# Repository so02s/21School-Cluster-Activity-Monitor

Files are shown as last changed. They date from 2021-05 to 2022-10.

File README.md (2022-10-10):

# 21School-Cluster-Activity-Monitor
### Description
In order to visualize clusters computers accesibility for students and make finding a coding place for oneself easier, School 21's Lab Manager Freimor (Ricky in School 21) came up with the idea of autonomous Cluster Activity Monitor.
It should be set up on each of the School's floors. We've managed to set it up on the 2nd floor.
Monitor has a map embedded in its graphics. It lights up LEDs, showing which Mac seats are occupied, which are free to use and other types of seat status. It's connected to a local network and pulls data from the metrics data-point server. 
* Monitor shows seats that are either taken, free, covid-free or used for exam.
* It also lights up the viewer's position on the map.
* Brightness of the LED is dependant on ambient light level, due to embedded light sensor.
* It should potentially support extra add-ons.



### Monitor consists of:
* 5 front PCB's which we call "modules", with school claster names (Atrium, Illusion, Oasis, Atlantis and Mirage)
  * ~450 SK9822 2020 leds
  * STM32F030* microcontroller
* 1 "motherboard" PCB
  * Raspberry Pi Zero W
  * ADS1115 for photoresistor
* Mean Well IRM-60-5ST power supply
* 3D printed skeleton structure
  * M1.2 inserted nuts and bolts for fixing modules in 3d printed front layer
  * M4 inserted nuts and bolts for fixing front layer to skeleton main body
  * 4 wall plug for fixing main body to wall
* Front PCB's shield made of polycarbonate sheet



<details><summary>Photos</summary>
<p>

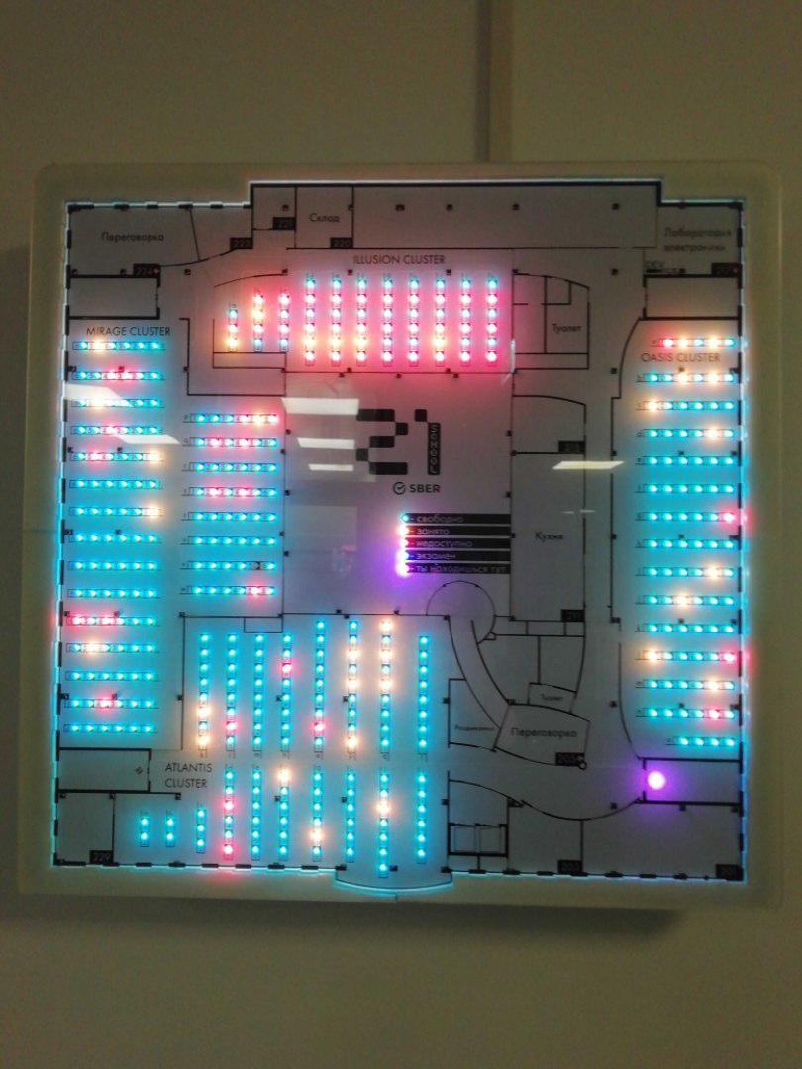
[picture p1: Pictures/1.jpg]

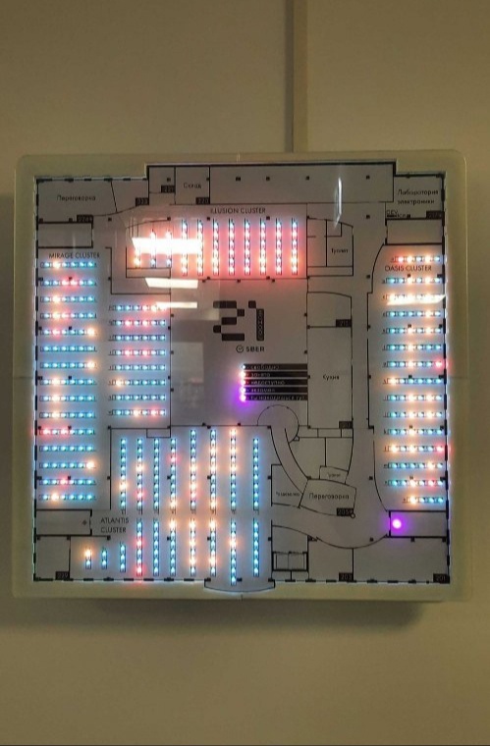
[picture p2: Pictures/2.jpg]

</p>
</details>

Done by team: Ricky, Bomanyte.

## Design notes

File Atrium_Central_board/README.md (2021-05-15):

# Atrium Central board layout

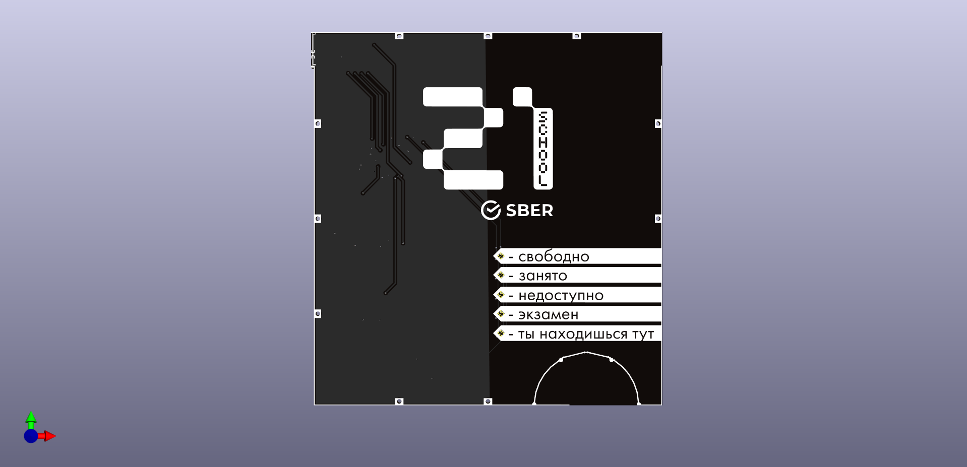
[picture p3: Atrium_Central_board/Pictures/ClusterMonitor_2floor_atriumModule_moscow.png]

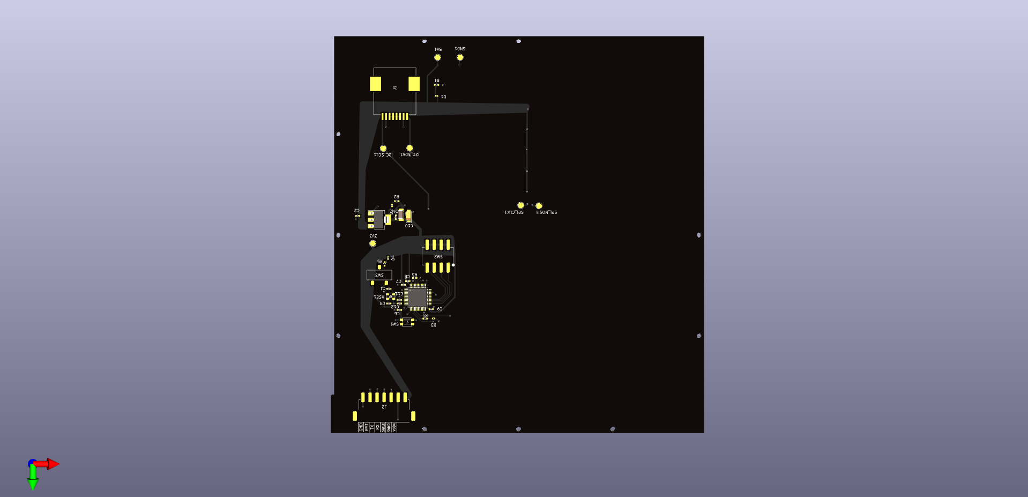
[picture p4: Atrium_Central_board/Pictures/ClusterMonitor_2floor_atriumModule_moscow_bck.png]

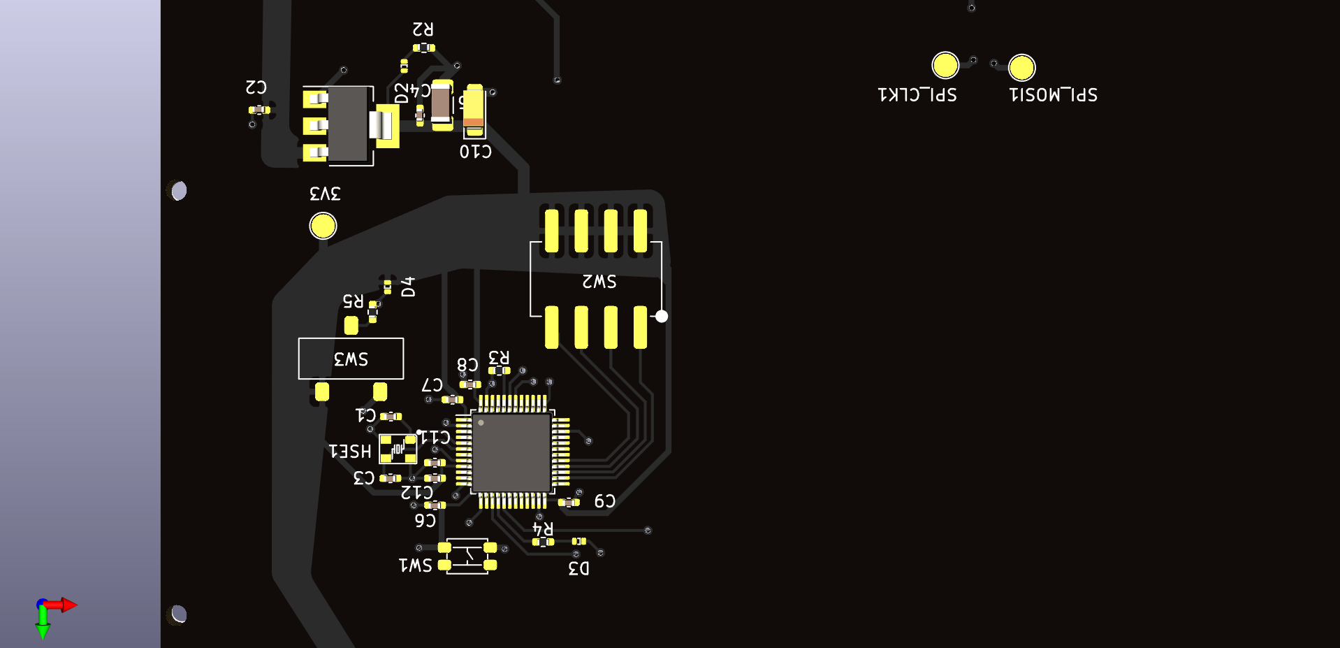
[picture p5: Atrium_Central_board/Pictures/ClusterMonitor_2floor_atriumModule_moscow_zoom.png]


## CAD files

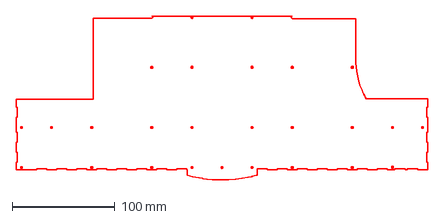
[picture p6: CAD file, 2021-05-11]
Atlantis_board/CM_2f_atlantis_outline_with_holes.dxf
400.0 x 159.3 mm

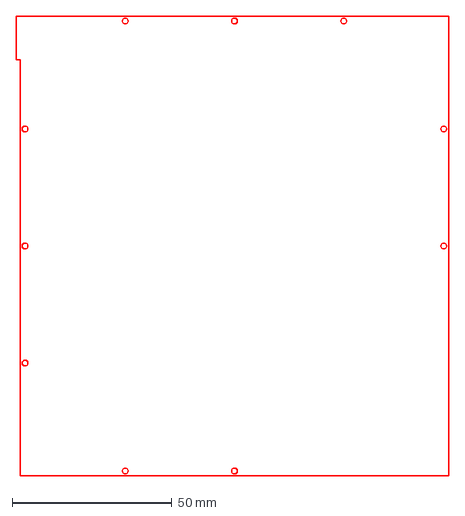
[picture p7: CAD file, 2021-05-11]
Atrium_Central_board/Silk/CM_2f_atrium_outline_with_holes.dxf
135.1 x 143.6 mm

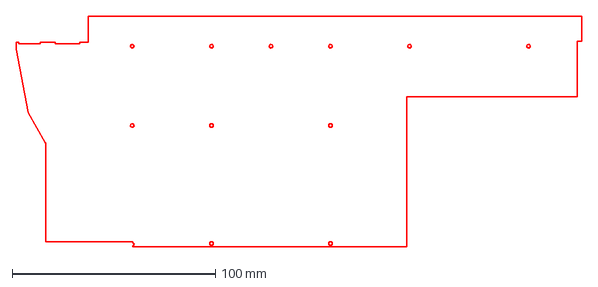
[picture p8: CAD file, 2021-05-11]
Illusion_board/CM_2f_illusion_outline_with_holes.dxf
278.6 x 113.3 mm

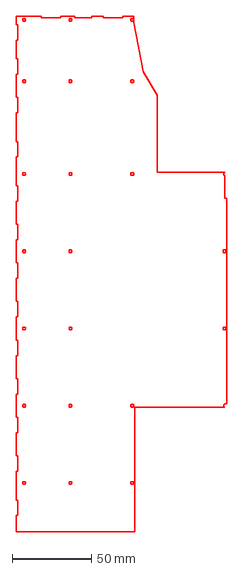
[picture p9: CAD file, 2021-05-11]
Mirage_board/CM_2f_mirage_outline_with_holes.dxf
132.8 x 325.5 mm

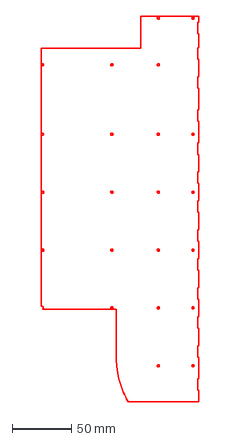
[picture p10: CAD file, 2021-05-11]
Oasis_board/CM_2f_oasis_outline_with_holes.dxf
132.8 x 325.1 mm

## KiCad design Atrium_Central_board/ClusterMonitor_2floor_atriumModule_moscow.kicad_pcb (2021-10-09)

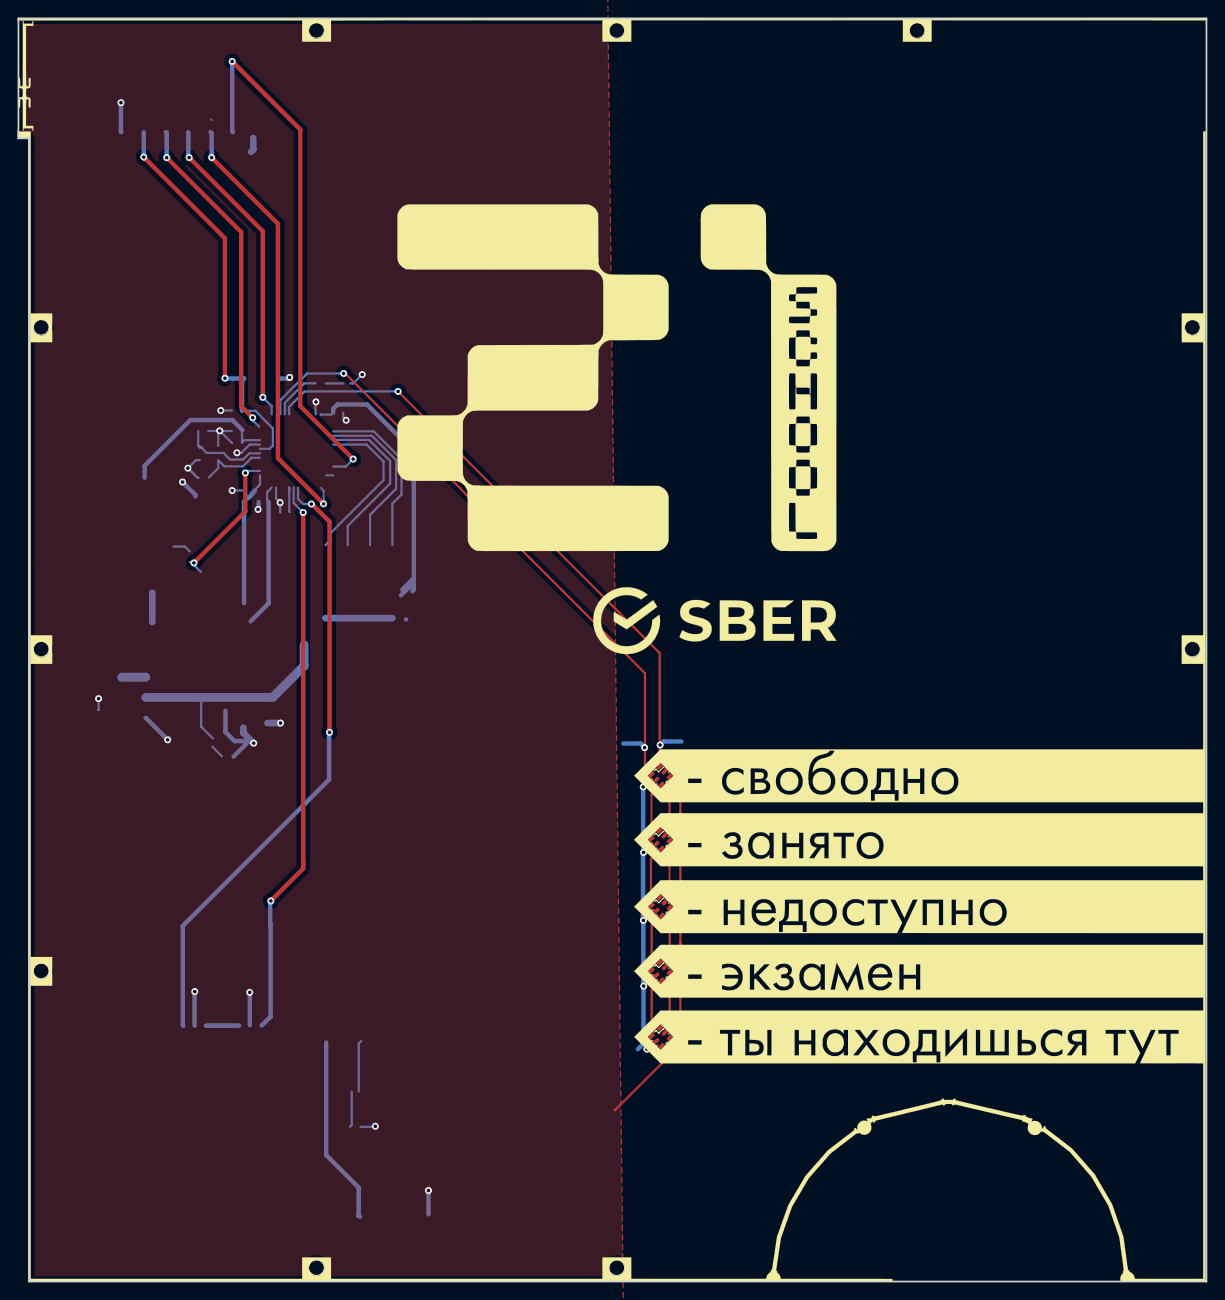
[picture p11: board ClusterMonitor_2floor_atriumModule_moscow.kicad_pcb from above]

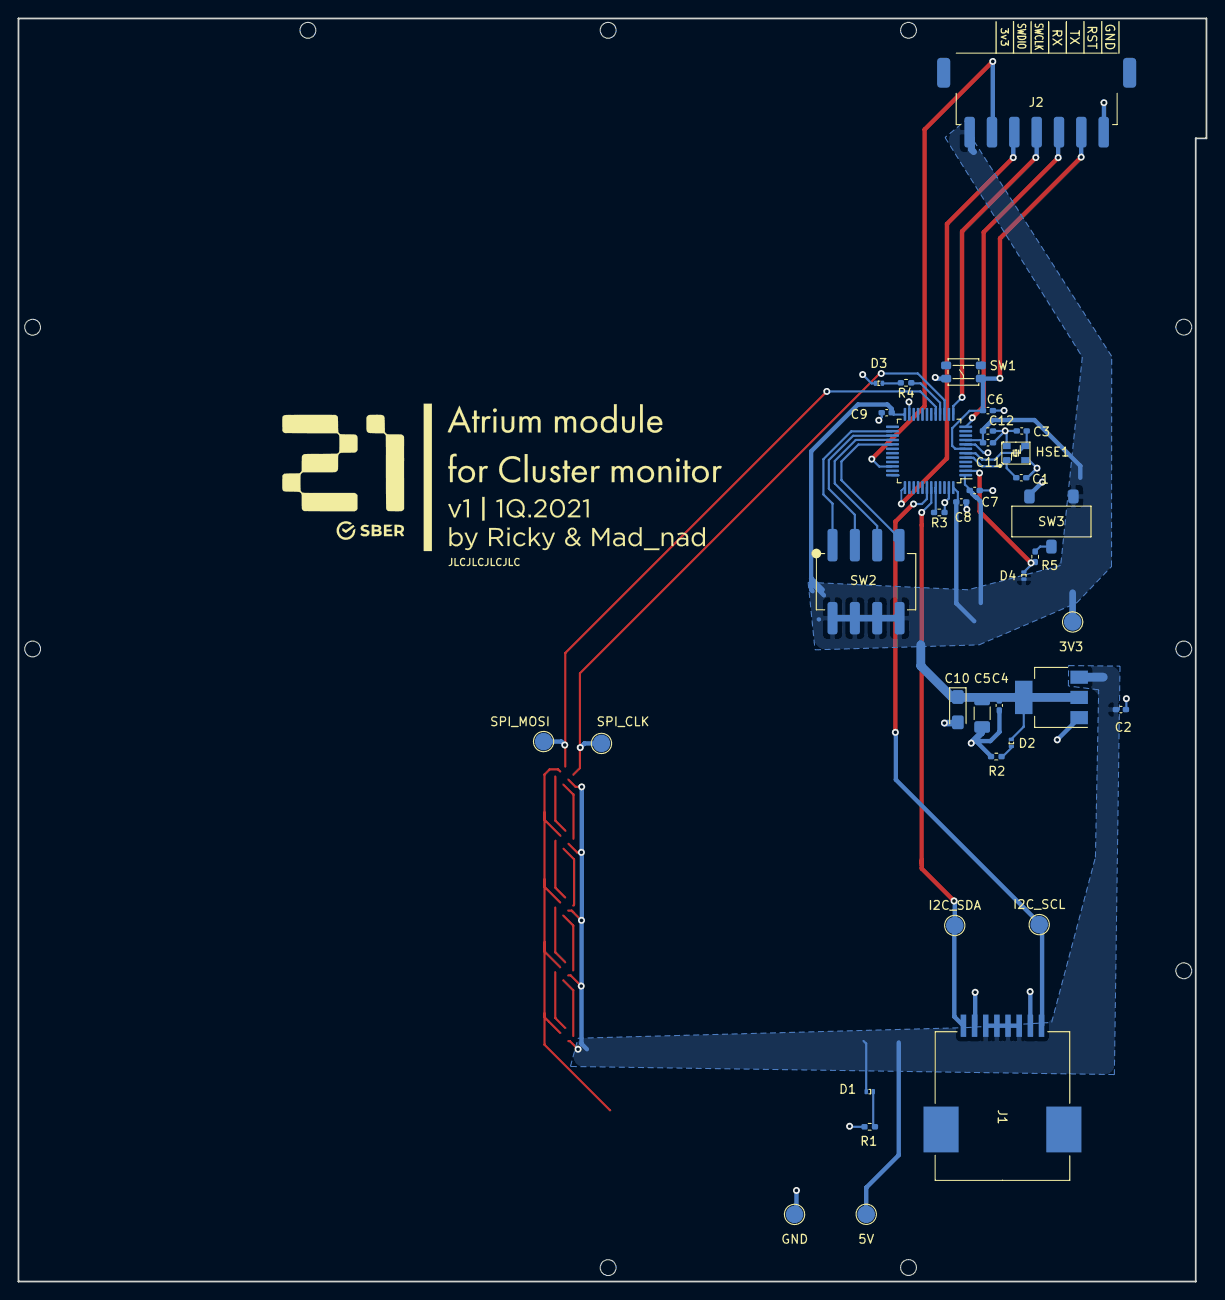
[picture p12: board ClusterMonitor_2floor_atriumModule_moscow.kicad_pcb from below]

Board: 2 copper layers, 135.1 x 143.6 mm, 41 parts (36 on the bottom side), 33 nets.

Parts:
3V3: TEST2; Pad_test
5V: TEST1; Pad_test
C1, C3: 15pF; C_0402_1005Metric_Pad0.74x0.62mm_HandSolder
C2, C4: 10uF; C_0402_1005Metric_Pad0.74x0.62mm_HandSolder
C5: 22uF tantal; C_1206_3216Metric_Pad1.33x1.80mm_HandSolder
C6: 0.1uF; C_0402_1005Metric_Pad0.74x0.62mm_HandSolder
C7, C8, C9: 100nF; C_0402_1005Metric_Pad0.74x0.62mm_HandSolder
C10: 4.7uF; CP_EIA-3216-10_Kemet-I_Pad1.58x1.35mm_HandSolder
C11: 10nF; C_0402_1005Metric_Pad0.74x0.62mm_HandSolder
C12: 1uF; C_0402_1005Metric_Pad0.74x0.62mm_HandSolder
D1: LED Blue (5v Power ON); LED_SMD_0402
D2: LED Red (3v3 Power ON); LED_SMD_0402
D3: Orange LED; LED_SMD_0402
D4: Purple LED; LED_SMD_0402
GND: TEST3; Pad_test
HSE1: Crystal_gnd24; ResonatorSMD_4pin(2,4GND)_KDS_1C232000AA0B
I2C_SCL: TEST4; Pad_test
I2C_SDA: TEST5; Pad_test
J1: RJ32_Shielded; rj45_molex_smd_44144-0003
J2: Conn_01x07; connector_7pin_xh2.54__lcsc_c146123_
LED1, LED2, LED3, LED4, LED5: SK9822-EC20
R1, R2, R4, R5: 1k5; R_0402_1005Metric_Pad0.72x0.64mm_HandSolder
R3: 10k; R_0402_1005Metric_Pad0.72x0.64mm_HandSolder
SPI_CLK: TEST6; Pad_test
SPI_MOSI: TEST7; Pad_test
SW1: SW_SPST; SW_SMD_XKB_(TS-1809SM-C)
SW2: ADDRESS_SELECT; SW_4poles_(LCSC_C3693)
SW3: SW_SPDT; SW_SMD_XKB_(SS-3235D-03-L1)
U1: AMS1117-3.3; SOT-223-3_TabPin2
U2: STM32F030C8Tx; LQFP-48_7x7mm_P0.5mm

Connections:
+5V: 5V.1, C2.1, D1.2, J1.3, J1.4, J1.5, J1.6, LED1.5, LED2.5, LED3.5, LED4.5, LED5.5, U1.3
C_RST: C6.2, J2.6, SW1.1, U2.7
GND: C1.2, C2.2, C3.2, C4.2, C5.2, C6.1, C7.2, C8.2, C9.2, C10.2, C11.2, C12.1, D3.1, GND.1, HSE1.2, HSE1.4, J1.2, J1.7, J2.7, LED1.2, LED2.2, LED3.2, LED4.2, LED5.2, R1.2, R2.2, R3.1, SW1.2, SW3.3, U1.1, U2.8, U2.23, U2.47
HSE_IN: C1.1, HSE1.1, U2.5
HSE_OUT: C3.1, HSE1.3, U2.6
I2C1_SCL: I2C_SCL.1, J1.8, U2.42
I2C1_SDA: I2C_SDA.1, J1.1, U2.43
unnamed: D1.1, R1.1
unnamed: D2.1, R2.1
unnamed: D3.2, R4.2
unnamed: LED1.1, LED2.3
unnamed: LED1.6, LED2.4
unnamed: LED2.1, LED3.3
unnamed: LED2.6, LED3.4
unnamed: LED3.1, LED4.3
unnamed: LED3.6, LED4.4
unnamed: LED4.1, LED5.3
unnamed: LED4.6, LED5.4
unnamed: R3.2, U2.44
unnamed: R4.1, U2.16
unnamed: R5.2, SW3.2
REG_1b: SW2.1, U2.26
REG_2b: SW2.2, U2.27
REG_3b: SW2.3, U2.28
REG_4b: SW2.4, U2.29
SPI1_CLK: LED1.4, SPI_CLK.1, U2.15
SPI1_MOSI: LED1.3, SPI_MOSI.1, U2.17
SWITCH_MODE: D4.1, R5.1, U2.2
SYS_JTCK-SWCLK: J2.3, U2.37
SYS_JTMS-SWDIO: J2.2, U2.34
USART2_RX: J2.4, U2.13
USART2_TX: J2.5, U2.12
VDDA: 3V3.1, C4.1, C5.1, C7.1, C8.1, C9.1, C10.1, C11.1, C12.2, D2.2, D4.2, J2.1, SW2.5, SW2.6, SW2.7, SW2.8, SW3.1, U1.2, U2.1, U2.9, U2.24, U2.48

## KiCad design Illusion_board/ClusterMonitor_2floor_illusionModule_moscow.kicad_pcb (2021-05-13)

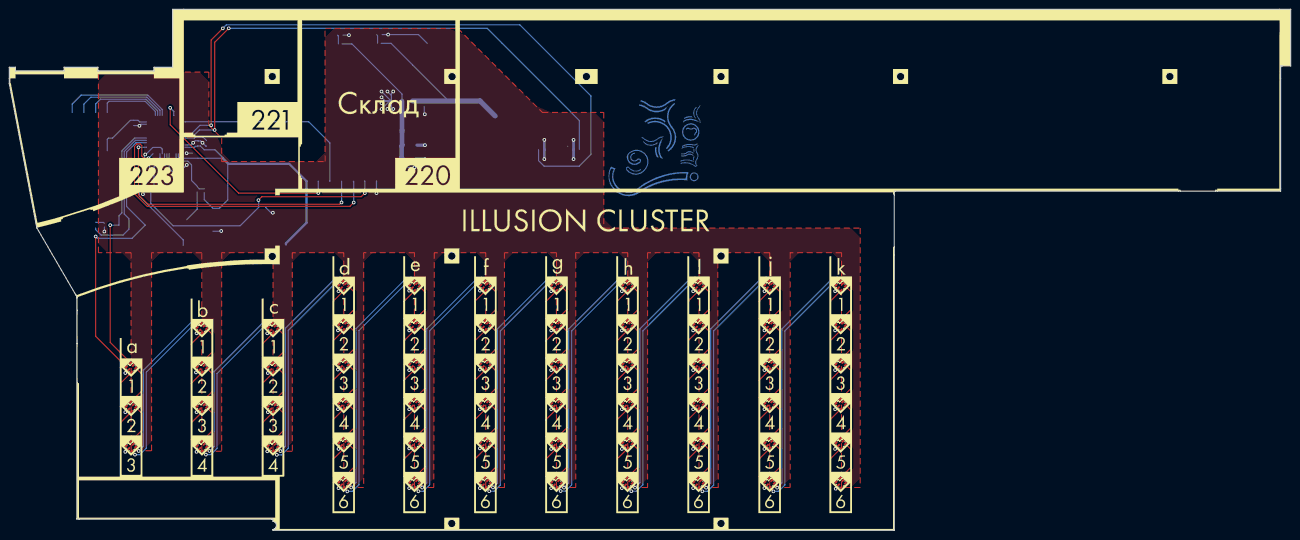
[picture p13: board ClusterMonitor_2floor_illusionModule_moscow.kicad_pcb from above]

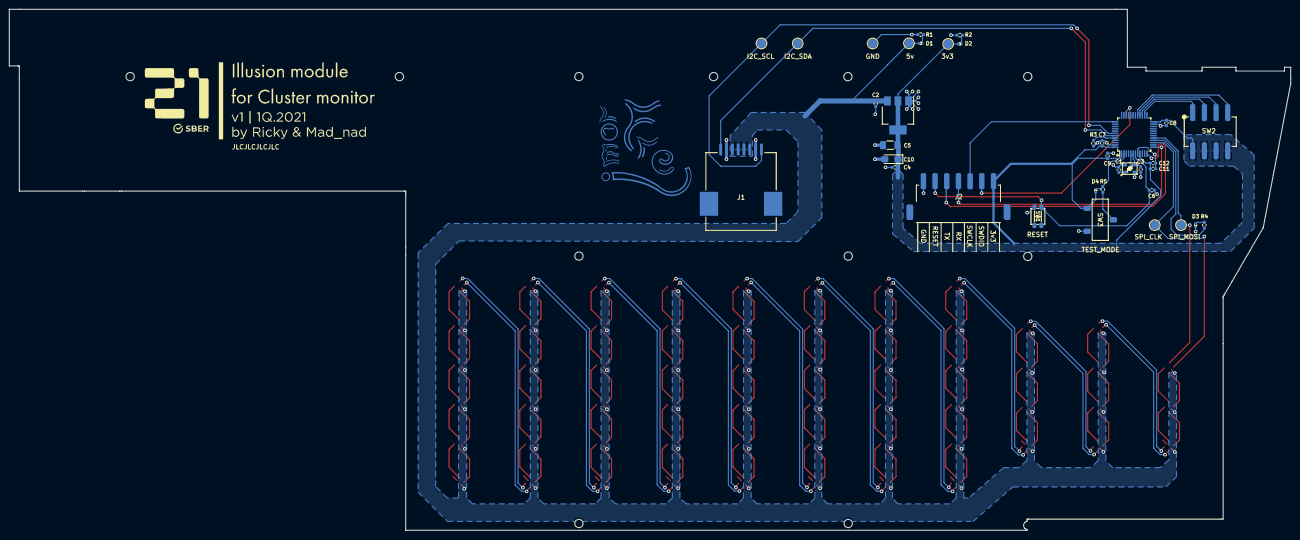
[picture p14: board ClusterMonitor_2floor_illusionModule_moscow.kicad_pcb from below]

Board: 2 copper layers, 278.6 x 113.3 mm, 95 parts (36 on the bottom side), 141 nets.

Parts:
C1, C3: 15pF; C_0402_1005Metric_Pad0.74x0.62mm_HandSolder
C2, C4: 10uF; C_0402_1005Metric_Pad0.74x0.62mm_HandSolder
C5: 22uF tantal; C_1206_3216Metric_Pad1.33x1.80mm_HandSolder
C6: 0.1uF; C_0402_1005Metric_Pad0.74x0.62mm_HandSolder
C7, C8, C9: 100nF; C_0402_1005Metric_Pad0.74x0.62mm_HandSolder
C10: 4.7uF; CP_EIA-3216-10_Kemet-I_Pad1.58x1.35mm_HandSolder
C11: 10nF; C_0402_1005Metric_Pad0.74x0.62mm_HandSolder
C12: 1uF; C_0402_1005Metric_Pad0.74x0.62mm_HandSolder
D1: LED Blue (5v Power ON); LED_SMD_0402
D2: LED Red (3v3 Power ON); LED_SMD_0402
D3: Orange LED; LED_SMD_0402
D4: Purple LED; LED_SMD_0402
HSE1: Crystal_gnd24; ResonatorSMD_4pin(2,4GND)_KDS_1C232000AA0B
J1: RJ45_Molex_smd_44144-0003
J2: Conn_01x07; Connector_7pin_XH2.54_(LCSC_C146123)
LED-a-1, LED-a-2, LED-a-3: SK9822-EC20
LED-b-1, LED-b-2, LED-b-3, LED-b-4: SK9822-EC20
LED-c-1, LED-c-2, LED-c-3, LED-c-4: SK9822-EC20
LED-d-1, LED-d-3, LED-d-4, LED-d-5, LED-d-6: SK9822-EC20
LED-d-e: SK9822-EC20
LED-e-1, LED-e-2, LED-e-3, LED-e-4, LED-e-5, LED-e-6: SK9822-EC20
LED-f-1, LED-f-2, LED-f-3, LED-f-4, LED-f-5, LED-f-6: SK9822-EC20
LED-g-1, LED-g-2, LED-g-3, LED-g-4, LED-g-5, LED-g-6: SK9822-EC20
LED-h-1, LED-h-2, LED-h-3, LED-h-4, LED-h-5, LED-h-6: SK9822-EC20
LED-i-1, LED-i-2, LED-i-3, LED-i-4, LED-i-5, LED-i-6: SK9822-EC20
LED-j-1, LED-j-2, LED-j-3, LED-j-4, LED-j-5, LED-j-6: SK9822-EC20
LED-k-1, LED-k-2, LED-k-3, LED-k-4, LED-k-5, LED-k-6: SK9822-EC20
R1, R2, R4, R5: 1k5; R_0402_1005Metric_Pad0.72x0.64mm_HandSolder
R3: 10k; R_0402_1005Metric_Pad0.72x0.64mm_HandSolder
SW1: SW_SPST_Double; SW_SMD_XKB_(TS-1809SM-C)
SW2: ADDRESS_SELECT; SW_4poles_(LCSC_C3693)
SW3: SW_SPDT; SW_SMD_XKB_(SS-3235D-03-L1)
TEST1, TEST2, TEST3, TEST4, TEST5, TEST6, TEST7: test_pad_circle2mm; Pad_test
U1: AMS1117-3.3; SOT-223-3_TabPin2
U2: STM32F030C8Tx; LQFP-48_7x7mm_P0.5mm

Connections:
+5V: C2.1, D1.2, J1.3, J1.4, J1.5, J1.6, LED-a-1.5, LED-a-2.5, LED-a-3.5, LED-b-1.5, LED-b-2.5, LED-b-3.5, LED-b-4.5, LED-c-1.5, LED-c-2.5, LED-c-3.5, LED-c-4.5, LED-d-1.5, LED-d-3.5, LED-d-4.5, LED-d-5.5, LED-d-6.5, LED-d-e.5, LED-e-1.5, LED-e-2.5, LED-e-3.5, LED-e-4.5, LED-e-5.5, LED-e-6.5, LED-f-1.5, LED-f-2.5, LED-f-3.5, LED-f-4.5, LED-f-5.5, LED-f-6.5, LED-g-1.5, LED-g-2.5, LED-g-3.5, LED-g-4.5, LED-g-5.5, LED-g-6.5, LED-h-1.5, LED-h-2.5, LED-h-3.5, LED-h-4.5, LED-h-5.5, LED-h-6.5, LED-i-1.5, LED-i-2.5, LED-i-3.5, LED-i-4.5, LED-i-5.5, LED-i-6.5, LED-j-1.5, LED-j-2.5, LED-j-3.5, LED-j-4.5, LED-j-5.5, LED-j-6.5, LED-k-1.5, LED-k-2.5, LED-k-3.5, LED-k-4.5, LED-k-5.5, LED-k-6.5, TEST1.1, U1.3
C_RST: C6.2, J2.6, SW1.1, U2.7
GND: C1.2, C2.2, C3.2, C4.2, C5.2, C6.1, C7.2, C8.2, C9.2, C10.2, C11.2, C12.1, D3.1, HSE1.2, HSE1.4, J1.2, J1.7, J2.7, LED-a-1.2, LED-a-2.2, LED-a-3.2, LED-b-1.2, LED-b-2.2, LED-b-3.2, LED-b-4.2, LED-c-1.2, LED-c-2.2, LED-c-3.2, LED-c-4.2, LED-d-1.2, LED-d-3.2, LED-d-4.2, LED-d-5.2, LED-d-6.2, LED-d-e.2, LED-e-1.2, LED-e-2.2, LED-e-3.2, LED-e-4.2, LED-e-5.2, LED-e-6.2, LED-f-1.2, LED-f-2.2, LED-f-3.2, LED-f-4.2, LED-f-5.2, LED-f-6.2, LED-g-1.2, LED-g-2.2, LED-g-3.2, LED-g-4.2, LED-g-5.2, LED-g-6.2, LED-h-1.2, LED-h-2.2, LED-h-3.2, LED-h-4.2, LED-h-5.2, LED-h-6.2, LED-i-1.2, LED-i-2.2, LED-i-3.2, LED-i-4.2, LED-i-5.2, LED-i-6.2, LED-j-1.2, LED-j-2.2, LED-j-3.2, LED-j-4.2, LED-j-5.2, LED-j-6.2, LED-k-1.2, LED-k-2.2, LED-k-3.2, LED-k-4.2, LED-k-5.2, LED-k-6.2, R1.2, R2.2, R3.1, SW1.3, SW3.3, TEST3.1, U1.1, U2.8, U2.23, U2.47
HSE_IN: C1.1, HSE1.1, U2.5
HSE_OUT: C3.1, HSE1.3, U2.6
I2C2_SCL: J1.8, TEST4.1, U2.42
I2C2_SDA: J1.1, TEST5.1, U2.43
unnamed: D1.1, R1.1
unnamed: D2.1, R2.1
unnamed: D3.2, R4.2
unnamed: LED-a-1.1, LED-a-2.3
unnamed: LED-a-1.6, LED-a-2.4
unnamed: LED-a-2.1, LED-a-3.3
unnamed: LED-a-2.6, LED-a-3.4
unnamed: LED-a-3.1, LED-b-1.3
unnamed: LED-a-3.6, LED-b-1.4
unnamed: LED-b-1.1, LED-b-2.3
unnamed: LED-b-1.6, LED-b-2.4
unnamed: LED-b-2.1, LED-b-3.3
unnamed: LED-b-2.6, LED-b-3.4
unnamed: LED-b-3.1, LED-b-4.3
unnamed: LED-b-3.6, LED-b-4.4
unnamed: LED-b-4.1, LED-c-1.3
unnamed: LED-b-4.6, LED-c-1.4
unnamed: LED-c-1.1, LED-c-2.3
unnamed: LED-c-1.6, LED-c-2.4
unnamed: LED-c-2.1, LED-c-3.3
unnamed: LED-c-2.6, LED-c-3.4
unnamed: LED-c-3.1, LED-c-4.3
unnamed: LED-c-3.6, LED-c-4.4
unnamed: LED-c-4.1, LED-d-1.3
unnamed: LED-c-4.6, LED-d-1.4
unnamed: LED-d-1.1, LED-d-e.3
unnamed: LED-d-1.6, LED-d-e.4
unnamed: LED-d-3.3, LED-d-e.1
unnamed: LED-d-3.4, LED-d-e.6
unnamed: LED-d-3.1, LED-d-4.3
unnamed: LED-d-3.6, LED-d-4.4
unnamed: LED-d-4.1, LED-d-5.3
unnamed: LED-d-4.6, LED-d-5.4
unnamed: LED-d-5.1, LED-d-6.3
unnamed: LED-d-5.6, LED-d-6.4
unnamed: LED-d-6.1, LED-e-1.3
unnamed: LED-d-6.6, LED-e-1.4
unnamed: LED-e-1.1, LED-e-2.3
unnamed: LED-e-1.6, LED-e-2.4
unnamed: LED-e-2.1, LED-e-3.3
unnamed: LED-e-2.6, LED-e-3.4
unnamed: LED-e-3.1, LED-e-4.3
unnamed: LED-e-3.6, LED-e-4.4
unnamed: LED-e-4.1, LED-e-5.3
unnamed: LED-e-4.6, LED-e-5.4
unnamed: LED-e-5.1, LED-e-6.3
unnamed: LED-e-5.6, LED-e-6.4
unnamed: LED-e-6.1, LED-f-1.3
unnamed: LED-e-6.6, LED-f-1.4
unnamed: LED-f-1.1, LED-f-2.3
unnamed: LED-f-1.6, LED-f-2.4
unnamed: LED-f-2.1, LED-f-3.3
unnamed: LED-f-2.6, LED-f-3.4
unnamed: LED-f-3.1, LED-f-4.3
unnamed: LED-f-3.6, LED-f-4.4
unnamed: LED-f-4.1, LED-f-5.3
unnamed: LED-f-4.6, LED-f-5.4
unnamed: LED-f-5.1, LED-f-6.3
unnamed: LED-f-5.6, LED-f-6.4
unnamed: LED-f-6.1, LED-g-1.3
unnamed: LED-f-6.6, LED-g-1.4
unnamed: LED-g-1.1, LED-g-2.3
unnamed: LED-g-1.6, LED-g-2.4
unnamed: LED-g-2.1, LED-g-3.3
unnamed: LED-g-2.6, LED-g-3.4
unnamed: LED-g-3.1, LED-g-4.3
unnamed: LED-g-3.6, LED-g-4.4
unnamed: LED-g-4.1, LED-g-5.3
unnamed: LED-g-4.6, LED-g-5.4
unnamed: LED-g-5.1, LED-g-6.3
unnamed: LED-g-5.6, LED-g-6.4
unnamed: LED-g-6.1, LED-h-1.3
unnamed: LED-g-6.6, LED-h-1.4
unnamed: LED-h-1.1, LED-h-2.3
unnamed: LED-h-1.6, LED-h-2.4
unnamed: LED-h-2.1, LED-h-3.3
unnamed: LED-h-2.6, LED-h-3.4
unnamed: LED-h-3.1, LED-h-4.3
unnamed: LED-h-3.6, LED-h-4.4
unnamed: LED-h-4.1, LED-h-5.3
unnamed: LED-h-4.6, LED-h-5.4
unnamed: LED-h-5.1, LED-h-6.3
unnamed: LED-h-5.6, LED-h-6.4
unnamed: LED-h-6.1, LED-i-1.3
unnamed: LED-h-6.6, LED-i-1.4
unnamed: LED-i-1.1, LED-i-2.3
unnamed: LED-i-1.6, LED-i-2.4
unnamed: LED-i-2.1, LED-i-3.3
unnamed: LED-i-2.6, LED-i-3.4
unnamed: LED-i-3.1, LED-i-4.3
unnamed: LED-i-3.6, LED-i-4.4
unnamed: LED-i-4.1, LED-i-5.3
unnamed: LED-i-4.6, LED-i-5.4
unnamed: LED-i-5.1, LED-i-6.3
unnamed: LED-i-5.6, LED-i-6.4
unnamed: LED-i-6.1, LED-j-1.3
unnamed: LED-i-6.6, LED-j-1.4
unnamed: LED-j-1.1, LED-j-2.3
unnamed: LED-j-1.6, LED-j-2.4
unnamed: LED-j-2.1, LED-j-3.3
unnamed: LED-j-2.6, LED-j-3.4
unnamed: LED-j-3.1, LED-j-4.3
unnamed: LED-j-3.6, LED-j-4.4
unnamed: LED-j-4.1, LED-j-5.3
unnamed: LED-j-4.6, LED-j-5.4
unnamed: LED-j-5.1, LED-j-6.3
unnamed: LED-j-5.6, LED-j-6.4
unnamed: LED-j-6.1, LED-k-1.3
unnamed: LED-j-6.6, LED-k-1.4
unnamed: LED-k-1.1, LED-k-2.3
unnamed: LED-k-1.6, LED-k-2.4
unnamed: LED-k-2.1, LED-k-3.3
unnamed: LED-k-2.6, LED-k-3.4
unnamed: LED-k-3.1, LED-k-4.3
unnamed: LED-k-3.6, LED-k-4.4
unnamed: LED-k-4.1, LED-k-5.3
unnamed: LED-k-4.6, LED-k-5.4
unnamed: LED-k-5.1, LED-k-6.3
unnamed: LED-k-5.6, LED-k-6.4
unnamed: R3.2, U2.44
unnamed: R4.1, U2.16
unnamed: R5.2, SW3.2
REG_1b: SW2.1, U2.26
REG_2b: SW2.2, U2.27
REG_3b: SW2.3, U2.28
REG_4b: SW2.4, U2.29
SPI1_CLK: LED-a-1.4, TEST6.1, U2.15
SPI1_MOSI: LED-a-1.3, TEST7.1, U2.17
SWITCH_MODE: D4.1, R5.1, U2.2
SYS_JTCK-SWCLK: J2.3, U2.37
SYS_JTMS-SWDIO: J2.2, U2.34
USART2_RX: J2.4, U2.13
USART2_TX: J2.5, U2.12
VDDA: C4.1, C5.1, C7.1, C8.1, C9.1, C10.1, C11.1, C12.2, D2.2, D4.2, J2.1, SW2.5, SW2.6, SW2.7, SW2.8, SW3.1, TEST2.1, U1.2, U2.1, U2.9, U2.24, U2.48

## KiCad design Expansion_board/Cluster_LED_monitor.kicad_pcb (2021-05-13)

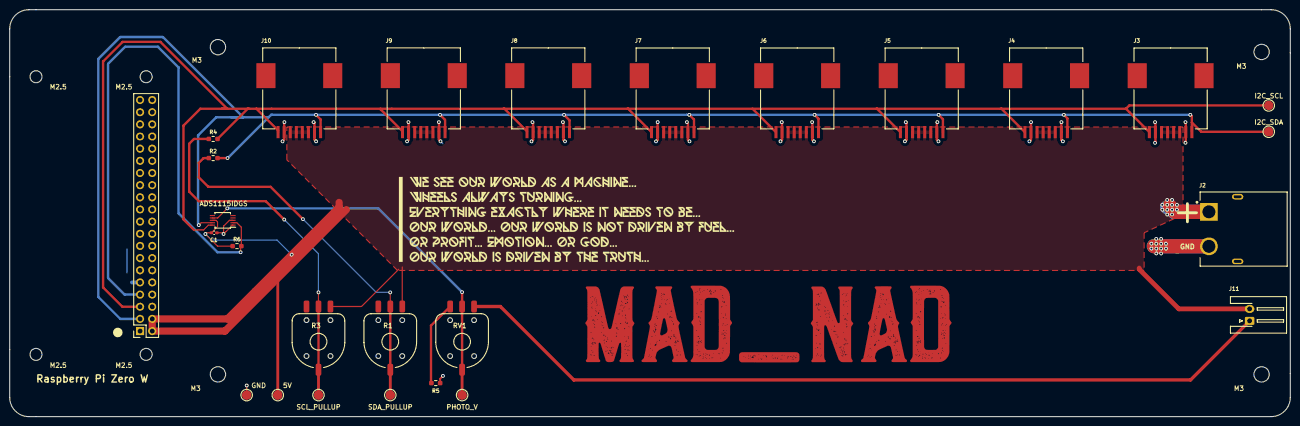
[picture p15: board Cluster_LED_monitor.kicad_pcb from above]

Board: 2 copper layers, 267.5 x 85.0 mm, 27 parts (0 on the bottom side), 10 nets.

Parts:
5V: TestPoint_Pad_D2.0mm
C1: 0.1uF; C_0402_1005Metric_Pad0.74x0.62mm_HandSolder
GND: TestPoint_Pad_D2.0mm
I2C_SCL, I2C_SDA: TestPoint_Pad_D2.0mm
J1: Raspberry_Pi_2_3; PinSocket_2x20_P2.54mm_Vertical
J2: Conn_01x02_Female; AMASS_XT60PW-M
J3, J4, J5, J6, J7, J8, J9, J10: RJ45; rj45_molex_smd_44144-0003
J11: Conn_01x02; JST_XH_S2B-XH-A-1_1x02_P2.50mm_Horizontal
PHOTO_V: TestPoint_Pad_D2.0mm
R1, R3: R_Variable; _var_res_RDC503013A
R2, R4, R5: 680; R_0603_1608Metric_Pad0.98x0.95mm_HandSolder
R6: 5K1; R_0603_1608Metric_Pad0.98x0.95mm_HandSolder
RV1: R_POT; _var_res_RDC503013A
SCL_PULLUP: TestPoint_Pad_D2.0mm
SDA_PULLUP: TestPoint_Pad_D2.0mm
U1: ADS1115IDGS; TSSOP-10_3x3mm_P0.5mm

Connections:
+5V: 5V.1, C1.1, J1.2, J1.4, J2.1, J3.3, J3.4, J3.5, J3.6, J4.3, J4.4, J4.5, J4.6, J5.3, J5.4, J5.5, J5.6, J6.3, J6.4, J6.5, J6.6, J7.3, J7.4, J7.5, J7.6, J8.3, J8.4, J8.5, J8.6, J9.3, J9.4, J9.5, J9.6, J10.3, J10.4, J10.5, J10.6, J11.2, R1.1, R3.1, R6.1, U1.8
GND: C1.2, GND.1, J1.6, J1.9, J1.14, J1.20, J1.25, J1.30, J1.34, J1.39, J2.2, J3.2, J3.7, J4.2, J4.7, J5.2, J5.7, J6.2, J6.7, J7.2, J7.7, J8.2, J8.7, J9.2, J9.7, J10.2, J10.7, R5.2, U1.1, U1.3
I2C_SCL: I2C_SCL.1, J1.5, J3.8, J4.8, J5.8, J6.8, J7.8, J8.8, J9.8, J10.8, R4.2, U1.10
I2C_SDA: I2C_SDA.1, J1.3, J3.1, J4.1, J5.1, J6.1, J7.1, J8.1, J9.1, J10.1, R2.2, U1.9
unnamed: J1.7, R6.2, U1.2
unnamed: J11.1, RV1.1
unnamed: R1.2, R2.1, SDA_PULLUP.1
unnamed: R3.2, R4.1, SCL_PULLUP.1
unnamed: R5.1, RV1.3
unnamed: PHOTO_V.1, RV1.2, U1.7

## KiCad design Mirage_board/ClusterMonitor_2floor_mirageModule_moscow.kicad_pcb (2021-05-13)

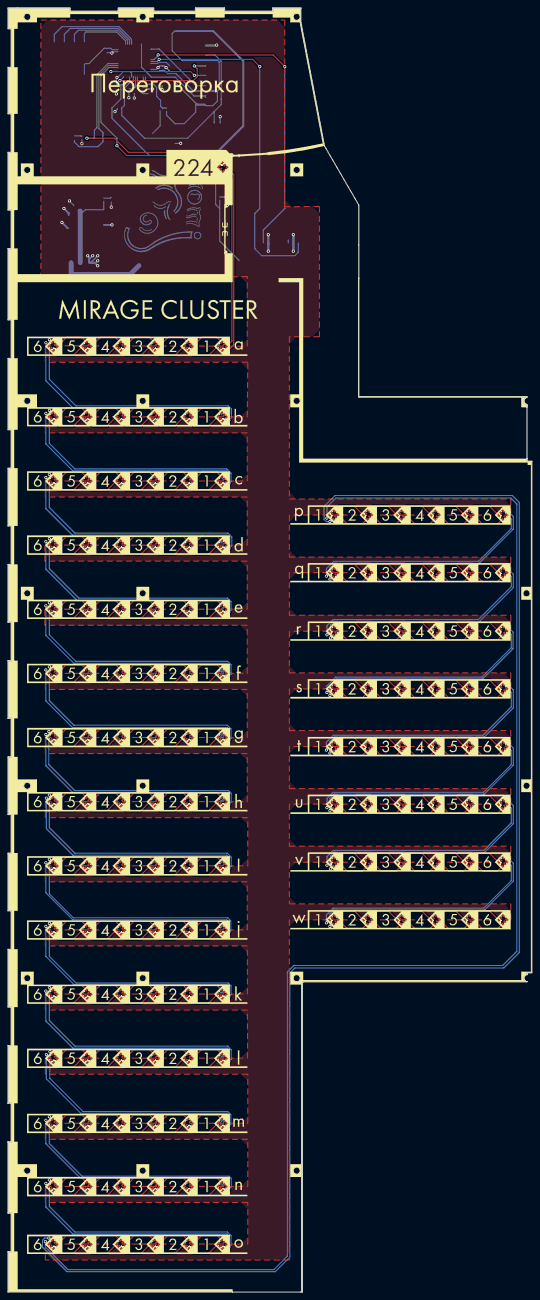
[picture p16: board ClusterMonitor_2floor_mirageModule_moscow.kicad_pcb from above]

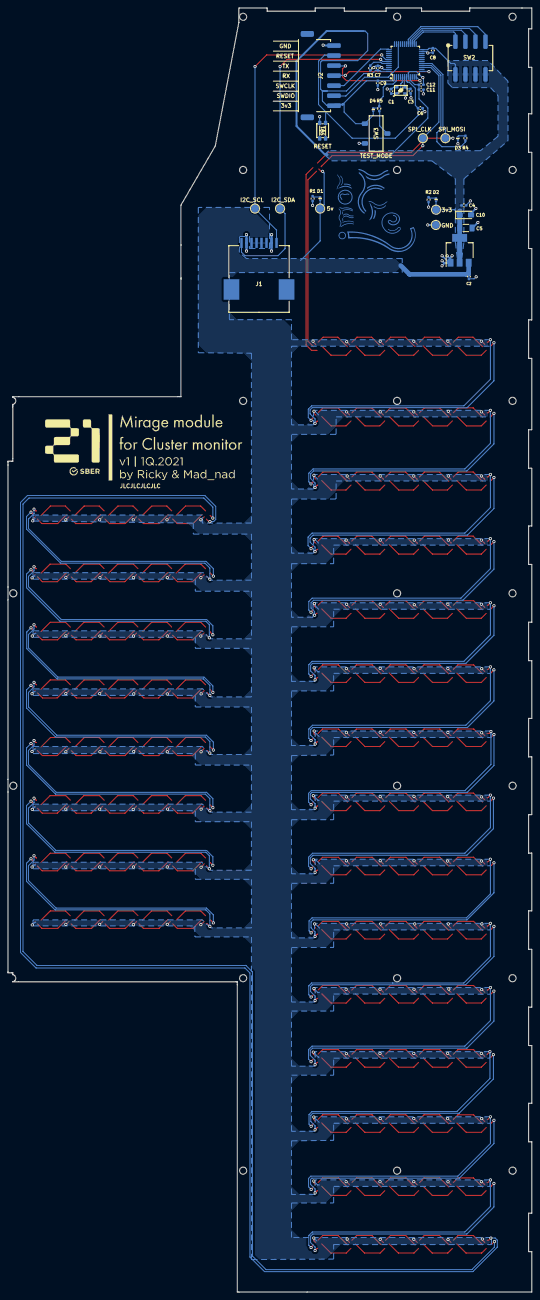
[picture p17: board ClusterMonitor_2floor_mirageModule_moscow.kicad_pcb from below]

Board: 2 copper layers, 132.8 x 325.5 mm, 175 parts (36 on the bottom side), 301 nets.

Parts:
C1, C3: 15pF; C_0402_1005Metric_Pad0.74x0.62mm_HandSolder
C2, C4: 10uF; C_0402_1005Metric_Pad0.74x0.62mm_HandSolder
C5: 22uF tantal; C_1206_3216Metric_Pad1.33x1.80mm_HandSolder
C6: 0.1uF; C_0402_1005Metric_Pad0.74x0.62mm_HandSolder
C7, C8, C9: 100nF; C_0402_1005Metric_Pad0.74x0.62mm_HandSolder
C10: 4.7uF; CP_EIA-3216-10_Kemet-I_Pad1.58x1.35mm_HandSolder
C11: 10nF; C_0402_1005Metric_Pad0.74x0.62mm_HandSolder
C12: 1uF; C_0402_1005Metric_Pad0.74x0.62mm_HandSolder
D1: LED Blue (5v Power ON); LED_SMD_0402
D2: LED Red (3v3 Power ON); LED_SMD_0402
D3: Orange LED; LED_SMD_0402
D4: Purple LED; LED_SMD_0402
HSE1: Crystal_gnd24; ResonatorSMD_4pin(2,4GND)_KDS_1C232000AA0B
J1: RJ45_Molex_smd_44144-0003
J2: Conn_01x07; Connector_7pin_XH2.54_(LCSC_C146123)
LED-a-1, LED-a-2, LED-a-3, LED-a-4, LED-a-5, LED-a-6: SK9822-EC20
LED-b-1, LED-b-2, LED-b-3, LED-b-4, LED-b-5, LED-b-6: SK9822-EC20
LED-c-1, LED-c-2, LED-c-3, LED-c-4, LED-c-5, LED-c-6: SK9822-EC20
LED-d-1, LED-d-2, LED-d-3, LED-d-4, LED-d-5, LED-d-6: SK9822-EC20
LED-e-1, LED-e-2, LED-e-3, LED-e-4, LED-e-5, LED-e-6: SK9822-EC20
LED-f-1, LED-f-2, LED-f-3, LED-f-4, LED-f-5, LED-f-6: SK9822-EC20
LED-g-1, LED-g-2, LED-g-3, LED-g-4, LED-g-5, LED-g-6: SK9822-EC20
LED-h-1, LED-h-2, LED-h-3, LED-h-4, LED-h-5, LED-h-6: SK9822-EC20
LED-i-1, LED-i-2, LED-i-3, LED-i-4, LED-i-5, LED-i-6: SK9822-EC20
LED-j-1, LED-j-2, LED-j-3, LED-j-4, LED-j-5, LED-j-6: SK9822-EC20
LED-k-1, LED-k-2, LED-k-3, LED-k-4, LED-k-5, LED-k-6: SK9822-EC20
LED-l-1, LED-l-2, LED-l-3, LED-l-4, LED-l-5, LED-l-6: SK9822-EC20
LED-m-1, LED-m-2, LED-m-3, LED-m-4, LED-m-5, LED-m-6: SK9822-EC20
LED-n-1, LED-n-2, LED-n-3, LED-n-4, LED-n-5, LED-n-6: SK9822-EC20
LED-o-1, LED-o-2, LED-o-3, LED-o-4, LED-o-5, LED-o-6: SK9822-EC20
LED-p-1, LED-p-2, LED-p-3, LED-p-4, LED-p-5, LED-p-6: SK9822-EC20
LED-peregov-0: SK9822-EC20
LED-q-1, LED-q-2, LED-q-3, LED-q-4, LED-q-5, LED-q-6: SK9822-EC20
LED-r-1, LED-r-2, LED-r-3, LED-r-4, LED-r-5, LED-r-6: SK9822-EC20
LED-s-1, LED-s-2, LED-s-3, LED-s-4, LED-s-5, LED-s-6: SK9822-EC20
LED-t-1, LED-t-2, LED-t-3, LED-t-4, LED-t-5, LED-t-6: SK9822-EC20
LED-u-1, LED-u-2, LED-u-3, LED-u-4, LED-u-5, LED-u-6: SK9822-EC20
LED-v-1, LED-v-2, LED-v-3, LED-v-4, LED-v-5, LED-v-6: SK9822-EC20
LED-w-1, LED-w-2, LED-w-3, LED-w-4, LED-w-5, LED-w-6: SK9822-EC20
R1, R2, R4, R5: 1k5; R_0402_1005Metric_Pad0.72x0.64mm_HandSolder
R3: 10k; R_0402_1005Metric_Pad0.72x0.64mm_HandSolder
SW1: SW_SPST_Double; SW_SMD_XKB_(TS-1809SM-C)
SW2: ADDRESS_SELECT; SW_4poles_(LCSC_C3693)
SW3: SW_SPDT; SW_SMD_XKB_(SS-3235D-03-L1)
TEST1, TEST2, TEST3, TEST4, TEST5, TEST6, TEST7: test_pad_circle2mm; Pad_test
U1: AMS1117-3.3; SOT-223-3_TabPin2
U2: STM32F030C8Tx; LQFP-48_7x7mm_P0.5mm

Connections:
+5V: C2.1, D1.2, J1.3, J1.4, J1.5, J1.6, LED-a-1.5, LED-a-2.5, LED-a-3.5, LED-a-4.5, LED-a-5.5, LED-a-6.5, LED-b-1.5, LED-b-2.5, LED-b-3.5, LED-b-4.5, LED-b-5.5, LED-b-6.5, LED-c-1.5, LED-c-2.5, LED-c-3.5, LED-c-4.5, LED-c-5.5, LED-c-6.5, LED-d-1.5, LED-d-2.5, LED-d-3.5, LED-d-4.5, LED-d-5.5, LED-d-6.5, LED-e-1.5, LED-e-2.5, LED-e-3.5, LED-e-4.5, LED-e-5.5, LED-e-6.5, LED-f-1.5, LED-f-2.5, LED-f-3.5, LED-f-4.5, LED-f-5.5, LED-f-6.5, LED-g-1.5, LED-g-2.5, LED-g-3.5, LED-g-4.5, LED-g-5.5, LED-g-6.5, LED-h-1.5, LED-h-2.5, LED-h-3.5, LED-h-4.5, LED-h-5.5, LED-h-6.5, LED-i-1.5, LED-i-2.5, LED-i-3.5, LED-i-4.5, LED-i-5.5, LED-i-6.5, LED-j-1.5, LED-j-2.5, LED-j-3.5, LED-j-4.5, LED-j-5.5, LED-j-6.5, LED-k-1.5, LED-k-2.5, LED-k-3.5, LED-k-4.5, LED-k-5.5, LED-k-6.5, LED-l-1.5, LED-l-2.5, LED-l-3.5, LED-l-4.5, LED-l-5.5, LED-l-6.5, LED-m-1.5, LED-m-2.5, LED-m-3.5, LED-m-4.5, LED-m-5.5, LED-m-6.5, LED-n-1.5, LED-n-2.5, LED-n-3.5, LED-n-4.5, LED-n-5.5, LED-n-6.5, LED-o-1.5, LED-o-2.5, LED-o-3.5, LED-o-4.5, LED-o-5.5, LED-o-6.5, LED-p-1.5, LED-p-2.5, LED-p-3.5, LED-p-4.5, LED-p-5.5, LED-p-6.5, LED-peregov-0.5, LED-q-1.5, LED-q-2.5, LED-q-3.5, LED-q-4.5, LED-q-5.5, LED-q-6.5, LED-r-1.5, LED-r-2.5, LED-r-3.5, LED-r-4.5, LED-r-5.5, LED-r-6.5, LED-s-1.5, LED-s-2.5, LED-s-3.5, LED-s-4.5, LED-s-5.5, LED-s-6.5, LED-t-1.5, LED-t-2.5, LED-t-3.5, LED-t-4.5, LED-t-5.5, LED-t-6.5, LED-u-1.5, LED-u-2.5, LED-u-3.5, LED-u-4.5, LED-u-5.5, LED-u-6.5, LED-v-1.5, LED-v-2.5, LED-v-3.5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
C_RST: C6.2, J2.6, SW1.1, U2.7
GND: C1.2, C2.2, C3.2, C4.2, C5.2, C6.1, C7.2, C8.2, C9.2, C10.2, C11.2, C12.1, D3.1, HSE1.2, HSE1.4, J1.2, J1.7, J2.7, LED-a-1.2, LED-a-2.2, LED-a-3.2, LED-a-4.2, LED-a-5.2, LED-a-6.2, LED-b-1.2, LED-b-2.2, LED-b-3.2, LED-b-4.2, LED-b-5.2, LED-b-6.2, LED-c-1.2, LED-c-2.2, LED-c-3.2, LED-c-4.2, LED-c-5.2, LED-c-6.2, LED-d-1.2, LED-d-2.2, LED-d-3.2, LED-d-4.2, LED-d-5.2, LED-d-6.2, LED-e-1.2, LED-e-2.2, LED-e-3.2, LED-e-4.2, LED-e-5.2, LED-e-6.2, LED-f-1.2, LED-f-2.2, LED-f-3.2, LED-f-4.2, LED-f-5.2, LED-f-6.2, LED-g-1.2, LED-g-2.2, LED-g-3.2, LED-g-4.2, LED-g-5.2, LED-g-6.2, LED-h-1.2, LED-h-2.2, LED-h-3.2, LED-h-4.2, LED-h-5.2, LED-h-6.2, LED-i-1.2, LED-i-2.2, LED-i-3.2, LED-i-4.2, LED-i-5.2, LED-i-6.2, LED-j-1.2, LED-j-2.2, LED-j-3.2, LED-j-4.2, LED-j-5.2, LED-j-6.2, LED-k-1.2, LED-k-2.2, LED-k-3.2, LED-k-4.2, LED-k-5.2, LED-k-6.2, LED-l-1.2, LED-l-2.2, LED-l-3.2, LED-l-4.2, LED-l-5.2, LED-l-6.2, LED-m-1.2, LED-m-2.2, LED-m-3.2, LED-m-4.2, LED-m-5.2, LED-m-6.2, LED-n-1.2, LED-n-2.2, LED-n-3.2, LED-n-4.2, LED-n-5.2, LED-n-6.2, LED-o-1.2, LED-o-2.2, LED-o-3.2, LED-o-4.2, LED-o-5.2, LED-o-6.2, LED-p-1.2, LED-p-2.2, LED-p-3.2, LED-p-4.2, LED-p-5.2, LED-p-6.2, LED-peregov-0.2, LED-q-1.2, LED-q-2.2, LED-q-3.2, LED-q-4.2, LED-q-5.2, LED-q-6.2, LED-r-1.2, LED-r-2.2, LED-r-3.2, LED-r-4.2, LED-r-5.2, LED-r-6.2, LED-s-1.2, LED-s-2.2, LED-s-3.2, LED-s-4.2, LED-s-5.2, LED-s-6.2, LED-t-1.2, LED-t-2.2, LED-t-3.2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
HSE_IN: C1.1, HSE1.1, U2.5
HSE_OUT: C3.1, HSE1.3, U2.6
I2C2_SCL: J1.8, TEST4.1, U2.42
I2C2_SDA: J1.1, TEST5.1, U2.43
unnamed: D1.1, R1.1
unnamed: D2.1, R2.1
unnamed: D3.2, R4.2
unnamed: LED-a-1.1, LED-a-2.3
unnamed: LED-a-1.3, LED-peregov-0.1
unnamed: LED-a-1.4, LED-peregov-0.6
unnamed: LED-a-1.6, LED-a-2.4
unnamed: LED-a-2.1, LED-a-3.3
unnamed: LED-a-2.6, LED-a-3.4
unnamed: LED-a-3.1, LED-a-4.3
unnamed: LED-a-3.6, LED-a-4.4
unnamed: LED-a-4.1, LED-a-5.3
unnamed: LED-a-4.6, LED-a-5.4
unnamed: LED-a-5.1, LED-a-6.3
unnamed: LED-a-5.6, LED-a-6.4
unnamed: LED-a-6.1, LED-b-1.3
unnamed: LED-a-6.6, LED-b-1.4
unnamed: LED-b-1.1, LED-b-2.3
unnamed: LED-b-1.6, LED-b-2.4
unnamed: LED-b-2.1, LED-b-3.3
unnamed: LED-b-2.6, LED-b-3.4
unnamed: LED-b-3.1, LED-b-4.3
unnamed: LED-b-3.6, LED-b-4.4
unnamed: LED-b-4.1, LED-b-5.3
unnamed: LED-b-4.6, LED-b-5.4
unnamed: LED-b-5.1, LED-b-6.3
unnamed: LED-b-5.6, LED-b-6.4
unnamed: LED-b-6.1, LED-c-1.3
unnamed: LED-b-6.6, LED-c-1.4
unnamed: LED-c-1.1, LED-c-2.3
unnamed: LED-c-1.6, LED-c-2.4
unnamed: LED-c-2.1, LED-c-3.3
unnamed: LED-c-2.6, LED-c-3.4
unnamed: LED-c-3.1, LED-c-4.3
unnamed: LED-c-3.6, LED-c-4.4
unnamed: LED-c-4.1, LED-c-5.3
unnamed: LED-c-4.6, LED-c-5.4
unnamed: LED-c-5.1, LED-c-6.3
unnamed: LED-c-5.6, LED-c-6.4
unnamed: LED-c-6.1, LED-d-1.3
unnamed: LED-c-6.6, LED-d-1.4
unnamed: LED-d-1.1, LED-d-2.3
unnamed: LED-d-1.6, LED-d-2.4
unnamed: LED-d-2.1, LED-d-3.3
unnamed: LED-d-2.6, LED-d-3.4
unnamed: LED-d-3.1, LED-d-4.3
unnamed: LED-d-3.6, LED-d-4.4
unnamed: LED-d-4.1, LED-d-5.3
unnamed: LED-d-4.6, LED-d-5.4
unnamed: LED-d-5.1, LED-d-6.3
unnamed: LED-d-5.6, LED-d-6.4
unnamed: LED-d-6.1, LED-e-1.3
unnamed: LED-d-6.6, LED-e-1.4
unnamed: LED-e-1.1, LED-e-2.3
unnamed: LED-e-1.6, LED-e-2.4
unnamed: LED-e-2.1, LED-e-3.3
unnamed: LED-e-2.6, LED-e-3.4
unnamed: LED-e-3.1, LED-e-4.3
unnamed: LED-e-3.6, LED-e-4.4
unnamed: LED-e-4.1, LED-e-5.3
unnamed: LED-e-4.6, LED-e-5.4
unnamed: LED-e-5.1, LED-e-6.3
unnamed: LED-e-5.6, LED-e-6.4
unnamed: LED-e-6.1, LED-f-1.3
unnamed: LED-e-6.6, LED-f-1.4
unnamed: LED-f-1.1, LED-f-2.3
unnamed: LED-f-1.6, LED-f-2.4
unnamed: LED-f-2.1, LED-f-3.3
unnamed: LED-f-2.6, LED-f-3.4
unnamed: LED-f-3.1, LED-f-4.3
unnamed: LED-f-3.6, LED-f-4.4
unnamed: LED-f-4.1, LED-f-5.3
unnamed: LED-f-4.6, LED-f-5.4
unnamed: LED-f-5.1, LED-f-6.3
unnamed: LED-f-5.6, LED-f-6.4
unnamed: LED-f-6.1, LED-g-1.3
unnamed: LED-f-6.6, LED-g-1.4
unnamed: LED-g-1.1, LED-g-2.3
unnamed: LED-g-1.6, LED-g-2.4
unnamed: LED-g-2.1, LED-g-3.3
unnamed: LED-g-2.6, LED-g-3.4
unnamed: LED-g-3.1, LED-g-4.3
unnamed: LED-g-3.6, LED-g-4.4
unnamed: LED-g-4.1, LED-g-5.3
unnamed: LED-g-4.6, LED-g-5.4
unnamed: LED-g-5.1, LED-g-6.3
unnamed: LED-g-5.6, LED-g-6.4
unnamed: LED-g-6.1, LED-h-1.3
unnamed: LED-g-6.6, LED-h-1.4
unnamed: LED-h-1.1, LED-h-2.3
unnamed: LED-h-1.6, LED-h-2.4
unnamed: LED-h-2.1, LED-h-3.3
unnamed: LED-h-2.6, LED-h-3.4
unnamed: LED-h-3.1, LED-h-4.3
unnamed: LED-h-3.6, LED-h-4.4
unnamed: LED-h-4.1, LED-h-5.3
unnamed: LED-h-4.6, LED-h-5.4
unnamed: LED-h-5.1, LED-h-6.3
unnamed: LED-h-5.6, LED-h-6.4
unnamed: LED-h-6.1, LED-i-1.3
unnamed: LED-h-6.6, LED-i-1.4
unnamed: LED-i-1.1, LED-i-2.3
unnamed: LED-i-1.6, LED-i-2.4
unnamed: LED-i-2.1, LED-i-3.3
unnamed: LED-i-2.6, LED-i-3.4
unnamed: LED-i-3.1, LED-i-4.3
unnamed: LED-i-3.6, LED-i-4.4
unnamed: LED-i-4.1, LED-i-5.3
unnamed: LED-i-4.6, LED-i-5.4
unnamed: LED-i-5.1, LED-i-6.3
unnamed: LED-i-5.6, LED-i-6.4
unnamed: LED-i-6.1, LED-j-1.3
unnamed: LED-i-6.6, LED-j-1.4
unnamed: LED-j-1.1, LED-j-2.3
unnamed: LED-j-1.6, LED-j-2.4
unnamed: LED-j-2.1, LED-j-3.3
unnamed: LED-j-2.6, LED-j-3.4
unnamed: LED-j-3.1, LED-j-4.3
unnamed: LED-j-3.6, LED-j-4.4
unnamed: LED-j-4.1, LED-j-5.3
unnamed: LED-j-4.6, LED-j-5.4
unnamed: LED-j-5.1, LED-j-6.3
unnamed: LED-j-5.6, LED-j-6.4
unnamed: LED-j-6.1, LED-k-1.3
unnamed: LED-j-6.6, LED-k-1.4
unnamed: LED-k-1.1, LED-k-2.3
unnamed: LED-k-1.6, LED-k-2.4
unnamed: LED-k-2.1, LED-k-3.3
unnamed: LED-k-2.6, LED-k-3.4
unnamed: LED-k-3.1, LED-k-4.3
unnamed: LED-k-3.6, LED-k-4.4
unnamed: LED-k-4.1, LED-k-5.3
unnamed: LED-k-4.6, LED-k-5.4
unnamed: LED-k-5.1, LED-k-6.3
unnamed: LED-k-5.6, LED-k-6.4
unnamed: LED-k-6.1, LED-l-1.3
unnamed: LED-k-6.6, LED-l-1.4
unnamed: LED-l-1.1, LED-l-2.3
unnamed: LED-l-1.6, LED-l-2.4
unnamed: LED-l-2.1, LED-l-3.3
unnamed: LED-l-2.6, LED-l-3.4
unnamed: LED-l-3.1, LED-l-4.3
unnamed: LED-l-3.6, LED-l-4.4
unnamed: LED-l-4.1, LED-l-5.3
unnamed: LED-l-4.6, LED-l-5.4
unnamed: LED-l-5.1, LED-l-6.3
unnamed: LED-l-5.6, LED-l-6.4
unnamed: LED-l-6.1, LED-m-1.3
unnamed: LED-l-6.6, LED-m-1.4
unnamed: LED-m-1.1, LED-m-2.3
unnamed: LED-m-1.6, LED-m-2.4
unnamed: LED-m-2.1, LED-m-3.3
unnamed: LED-m-2.6, LED-m-3.4
unnamed: LED-m-3.1, LED-m-4.3
unnamed: LED-m-3.6, LED-m-4.4
unnamed: LED-m-4.1, LED-m-5.3
unnamed: LED-m-4.6, LED-m-5.4
unnamed: LED-m-5.1, LED-m-6.3
unnamed: LED-m-5.6, LED-m-6.4
unnamed: LED-m-6.1, LED-n-1.3
unnamed: LED-m-6.6, LED-n-1.4
unnamed: LED-n-1.1, LED-n-2.3
unnamed: LED-n-1.6, LED-n-2.4
unnamed: LED-n-2.1, LED-n-3.3
unnamed: LED-n-2.6, LED-n-3.4
unnamed: LED-n-3.1, LED-n-4.3
unnamed: LED-n-3.6, LED-n-4.4
unnamed: LED-n-4.1, LED-n-5.3
unnamed: LED-n-4.6, LED-n-5.4
unnamed: LED-n-5.1, LED-n-6.3
unnamed: LED-n-5.6, LED-n-6.4
unnamed: LED-n-6.1, LED-o-1.3
unnamed: LED-n-6.6, LED-o-1.4
unnamed: LED-o-1.1, LED-o-2.3
unnamed: LED-o-1.6, LED-o-2.4
unnamed: LED-o-2.1, LED-o-3.3
unnamed: LED-o-2.6, LED-o-3.4
unnamed: LED-o-3.1, LED-o-4.3
unnamed: LED-o-3.6, LED-o-4.4
unnamed: LED-o-4.1, LED-o-5.3
unnamed: LED-o-4.6, LED-o-5.4
unnamed: LED-o-5.1, LED-o-6.3
unnamed: LED-o-5.6, LED-o-6.4
unnamed: LED-o-6.1, LED-p-1.3
unnamed: LED-o-6.6, LED-p-1.4
unnamed: LED-p-1.1, LED-p-2.3
unnamed: LED-p-1.6, LED-p-2.4
unnamed: LED-p-2.1, LED-p-3.3
unnamed: LED-p-2.6, LED-p-3.4
unnamed: LED-p-3.1, LED-p-4.3
unnamed: LED-p-3.6, LED-p-4.4
unnamed: LED-p-4.1, LED-p-5.3
unnamed: LED-p-4.6, LED-p-5.4
unnamed: LED-p-5.1, LED-p-6.3
unnamed: LED-p-5.6, LED-p-6.4
unnamed: LED-p-6.1, LED-q-1.3
unnamed: LED-p-6.6, LED-q-1.4
unnamed: LED-q-1.1, LED-q-2.3
unnamed: LED-q-1.6, LED-q-2.4
unnamed: LED-q-2.1, LED-q-3.3
unnamed: LED-q-2.6, LED-q-3.4
unnamed: LED-q-3.1, LED-q-4.3
unnamed: LED-q-3.6, LED-q-4.4
unnamed: LED-q-4.1, LED-q-5.3
unnamed: LED-q-4.6, LED-q-5.4
unnamed: LED-q-5.1, LED-q-6.3
unnamed: LED-q-5.6, LED-q-6.4
unnamed: LED-q-6.1, LED-r-1.3
unnamed: LED-q-6.6, LED-r-1.4
unnamed: LED-r-1.1, LED-r-2.3
unnamed: LED-r-1.6, LED-r-2.4
unnamed: LED-r-2.1, LED-r-3.3
unnamed: LED-r-2.6, LED-r-3.4
unnamed: LED-r-3.1, LED-r-4.3
unnamed: LED-r-3.6, LED-r-4.4
unnamed: LED-r-4.1, LED-r-5.3
unnamed: LED-r-4.6, LED-r-5.4
unnamed: LED-r-5.1, LED-r-6.3
unnamed: LED-r-5.6, LED-r-6.4
unnamed: LED-r-6.1, LED-s-1.3
unnamed: LED-r-6.6, LED-s-1.4
unnamed: LED-s-1.1, LED-s-2.3
unnamed: LED-s-1.6, LED-s-2.4
unnamed: LED-s-2.1, LED-s-3.3
unnamed: LED-s-2.6, LED-s-3.4
unnamed: LED-s-3.1, LED-s-4.3
unnamed: LED-s-3.6, LED-s-4.4
unnamed: LED-s-4.1, LED-s-5.3
unnamed: LED-s-4.6, LED-s-5.4
unnamed: LED-s-5.1, LED-s-6.3
unnamed: LED-s-5.6, LED-s-6.4
unnamed: LED-s-6.1, LED-t-1.3
unnamed: LED-s-6.6, LED-t-1.4
unnamed: LED-t-1.1, LED-t-2.3
unnamed: LED-t-1.6, LED-t-2.4
unnamed: LED-t-2.1, LED-t-3.3
unnamed: LED-t-2.6, LED-t-3.4
unnamed: LED-t-3.1, LED-t-4.3
unnamed: LED-t-3.6, LED-t-4.4
unnamed: LED-t-4.1, LED-t-5.3
unnamed: LED-t-4.6, LED-t-5.4
unnamed: LED-t-5.1, LED-t-6.3
unnamed: LED-t-5.6, LED-t-6.4
unnamed: LED-t-6.1, LED-u-1.3
unnamed: LED-t-6.6, LED-u-1.4
unnamed: LED-u-1.1, LED-u-2.3
unnamed: LED-u-1.6, LED-u-2.4
unnamed: LED-u-2.1, LED-u-3.3
unnamed: LED-u-2.6, LED-u-3.4
unnamed: LED-u-3.1, LED-u-4.3
unnamed: LED-u-3.6, LED-u-4.4
unnamed: LED-u-4.1, LED-u-5.3
unnamed: LED-u-4.6, LED-u-5.4
unnamed: LED-u-5.1, LED-u-6.3
unnamed: LED-u-5.6, LED-u-6.4
unnamed: LED-u-6.1, LED-v-1.3
unnamed: LED-u-6.6, LED-v-1.4
unnamed: LED-v-1.1, LED-v-2.3
unnamed: LED-v-1.6, LED-v-2.4
unnamed: LED-v-2.1, LED-v-3.3
unnamed: LED-v-2.6, LED-v-3.4
unnamed: LED-v-3.1, LED-v-4.3
unnamed: LED-v-3.6, LED-v-4.4
unnamed: LED-v-4.1, LED-v-5.3
unnamed: LED-v-4.6, LED-v-5.4
unnamed: LED-v-5.1, LED-v-6.3
unnamed: LED-v-5.6, LED-v-6.4
unnamed: LED-v-6.1, LED-w-1.3
unnamed: LED-v-6.6, LED-w-1.4
unnamed: LED-w-1.1, LED-w-2.3
unnamed: LED-w-1.6, LED-w-2.4
unnamed: LED-w-2.1, LED-w-3.3
unnamed: LED-w-2.6, LED-w-3.4
unnamed: LED-w-3.1, LED-w-4.3
unnamed: LED-w-3.6, LED-w-4.4
unnamed: LED-w-4.1, LED-w-5.3
unnamed: LED-w-4.6, LED-w-5.4
unnamed: LED-w-5.1, LED-w-6.3
unnamed: LED-w-5.6, LED-w-6.4
unnamed: R3.2, U2.44
unnamed: R4.1, U2.16
unnamed: R5.2, SW3.2
REG_1b: SW2.1, U2.26
REG_2b: SW2.2, U2.27
REG_3b: SW2.3, U2.28
REG_4b: SW2.4, U2.29
SPI1_CLK: LED-peregov-0.4, TEST6.1, U2.15
SPI1_MOSI: LED-peregov-0.3, TEST7.1, U2.17
SWITCH_MODE: D4.1, R5.1, U2.2
SYS_JTCK-SWCLK: J2.3, U2.37
SYS_JTMS-SWDIO: J2.2, U2.34
USART2_RX: J2.4, U2.13
USART2_TX: J2.5, U2.12
VDDA: C4.1, C5.1, C7.1, C8.1, C9.1, C10.1, C11.1, C12.2, D2.2, D4.2, J2.1, SW2.5, SW2.6, SW2.7, SW2.8, SW3.1, TEST2.1, U1.2, U2.1, U2.9, U2.24, U2.48

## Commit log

2021-04-28 Expansion board
    [Cluster_LED_monitor.kicad_pcb, Cluster_LED_monitor.sch]
2021-04-28 Atrium PCB
    [ClusterMonitor_2floor_atriumModule_moscow.kicad_pcb, ClusterMonitor_2floor_atriumModule_moscow.sch, matrix_atrium.sch]
2021-04-28 Footprints added
2021-05-11 Add project files 11.05.21
    [CM_2f_atlantis_outline_with_holes.dxf, CM_2f_atrium_outline_with_holes.dxf, CM_2f_illusion_outline_with_holes.dxf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]
2021-05-13 Some changes
    Add stencil board layout.
    Add gerbers.
    Minor changes in expancion and atrium board.
    [ClusterMonitor_2floor_atlantisModule_moscow.kicad_pcb, ClusterMonitor_2floor_atriumModule_moscow.kicad_pcb, ClusterMonitor_2floor_atriumModule_moscow.sch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]
2021-05-13 Atrium pcb bomanyte version
    [ClusterMonitor_2floor_atriumModule_moscow_ricky_version.kicad_pcb]
2021-05-15 Atrium pcb tweaking
    [CM_2f_atrium_outline_with_holes.dxf, ClusterMonitor_2floor_atriumModule_moscow.kicad_pcb]
2021-05-15 Oops forgot to change smth
    [ClusterMonitor_2floor_atriumModule_moscow.kicad_pcb]
2021-10-09 Add STM32 firmware
    [ClusterMonitor_2floor_atriumModule_moscow.kicad_pcb, ClusterMonitor_2floor_atriumModule_moscow_stencil.kicad_pcb]
2021-10-10 Nothing important, just switching to vscode
2021-11-14 Code for Raspberry
2021-11-28 Added ADC brightness level processing.
2022-08-18 Newer update. Change raspberry zero to 3b+
